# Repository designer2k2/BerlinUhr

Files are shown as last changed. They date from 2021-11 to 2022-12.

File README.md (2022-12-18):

# BerlinUhr
Berlin Uhr or Mengenlehreuhr, a fancy retro style clock that's a bit tricky to read: https://en.wikipedia.org/wiki/Mengenlehreuhr

## What is this

The BerlinUhr is a standalone PCB with all the needed parts on it, just connect power over the USB-C and it will run.

The [ATtiny167](https://www.microchip.com/ATtiny167) receives the actual time from the [DS3231](https://www.maximintegrated.com/en/products/analog/real-time-clocks/DS3231M.html) real time clock chip. Then displays it with 24 leds driven by the [TLC5947](https://www.ti.com/product/TLC5947). The brightness is adopted by measuring the ambient light with a [KPS-3227](https://www.kingbright.com/attachments/file/psearch/000/00/watermark00/KPS-3227SP1C(Ver.9).pdf). 

## Building it

1. PCB, source it with the gerbers: https://github.com/designer2k2/BerlinUhr/tree/main/Berlin_Uhr/gerber
2. Schematic: https://github.com/designer2k2/BerlinUhr/blob/main/Berlin_Uhr/Schematic.pdf
3. BOM, interactive BOM here: https://github.com/designer2k2/BerlinUhr/tree/main/Berlin_Uhr/bom
4. Bootloader, burn the [Micronucleus](https://github.com/micronucleus/micronucleus) Bootloader to the ATtiny167 with ISP: https://github.com/ArminJo/DigistumpArduino 
5. Insert CR1216 battery for the RTC to keep time also while the USB power is gone.
6. Software, upload the Code from the scr folder: https://github.com/designer2k2/BerlinUhr/tree/main/src/berlin-uhr 

## Setting the time

1. The time gets set the first time the code is uploaded to the time from the pc.
2. To change it afterwards, push the A and B buttons on the edge / backside.

## Reading the time

This is special on the Berlin Clock. A practical explanation is given in the wikipedia article: https://en.wikipedia.org/wiki/Mengenlehreuhr#Time_encoding

The Berlin Clock is easy to read after a couple of days :-)

## Modifying it

- The PCB is made with KiCad (6.0.2): http://www.kicad-pcb.org/
- The PCB-Art graphics are made with Inkscape: https://inkscape.org/
- Parts of the graphics are converted to Footprints with svg2mod: https://github.com/mtl/svg2mod
- The BOM is made with InteractiveHtmlBom: https://github.com/openscopeproject/InteractiveHtmlBom

KiCad Version of at least 6.0.2 is needed due to a bug in the KPS-3227 Footprint in older Versions: https://gitlab.com/kicad/libraries/kicad-symbols/-/issues/3164

## How it looks

grafik

Its 17:45 :smiley:

It can hang on a wall or sit on a table with the help of a USB-C phone docking station.

The bare PCB:

grafik

ISP Programming the Bootloader to the ATtiny with the help of a Arduino Uno:

grafik

Populated backside:

grafik

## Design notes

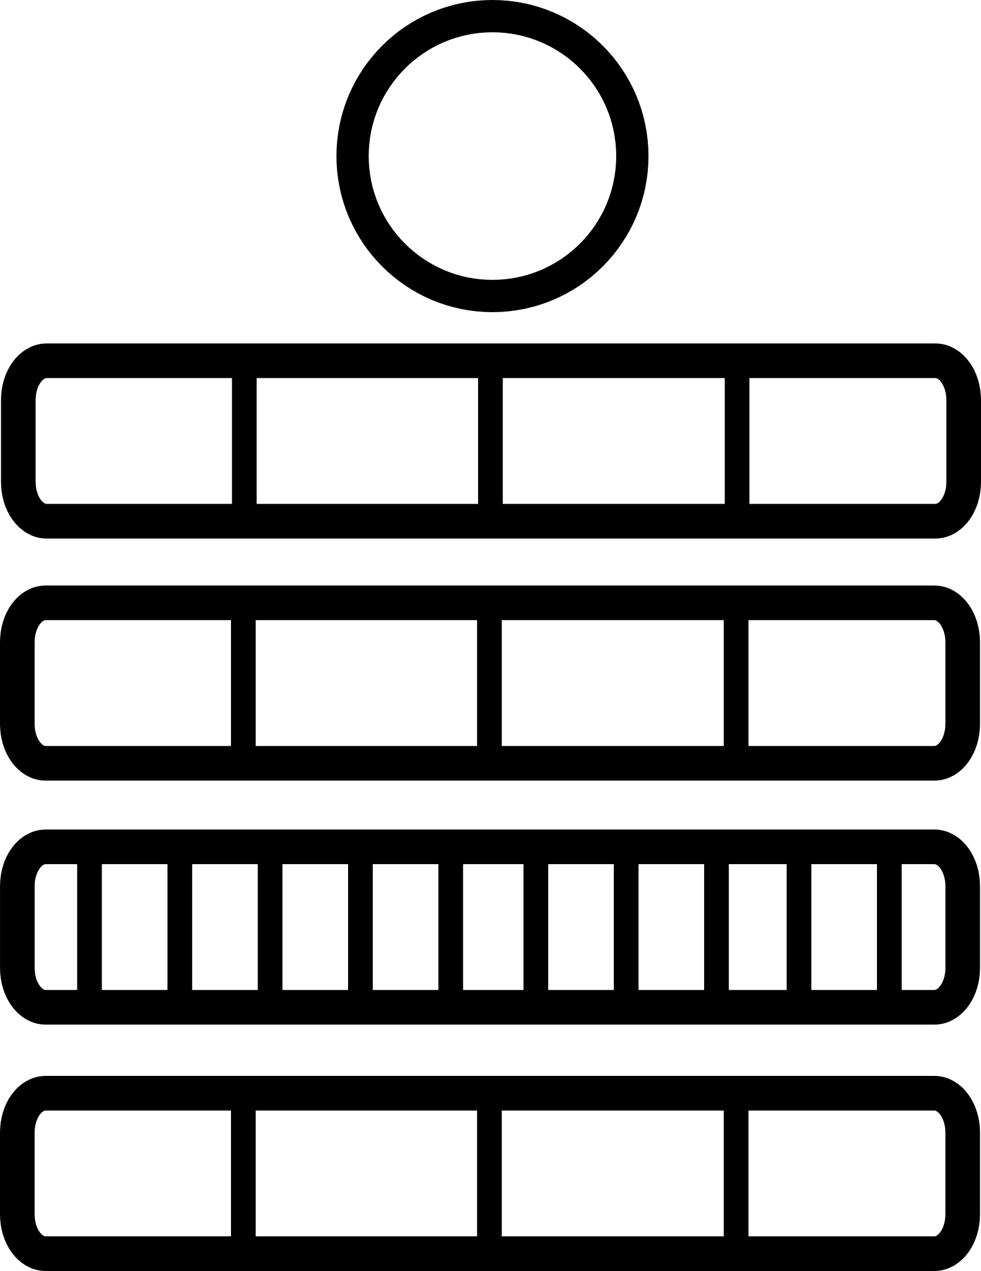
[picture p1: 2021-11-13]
Berlin_Uhr/images/Berlin_Uhr-LED-Frame.png

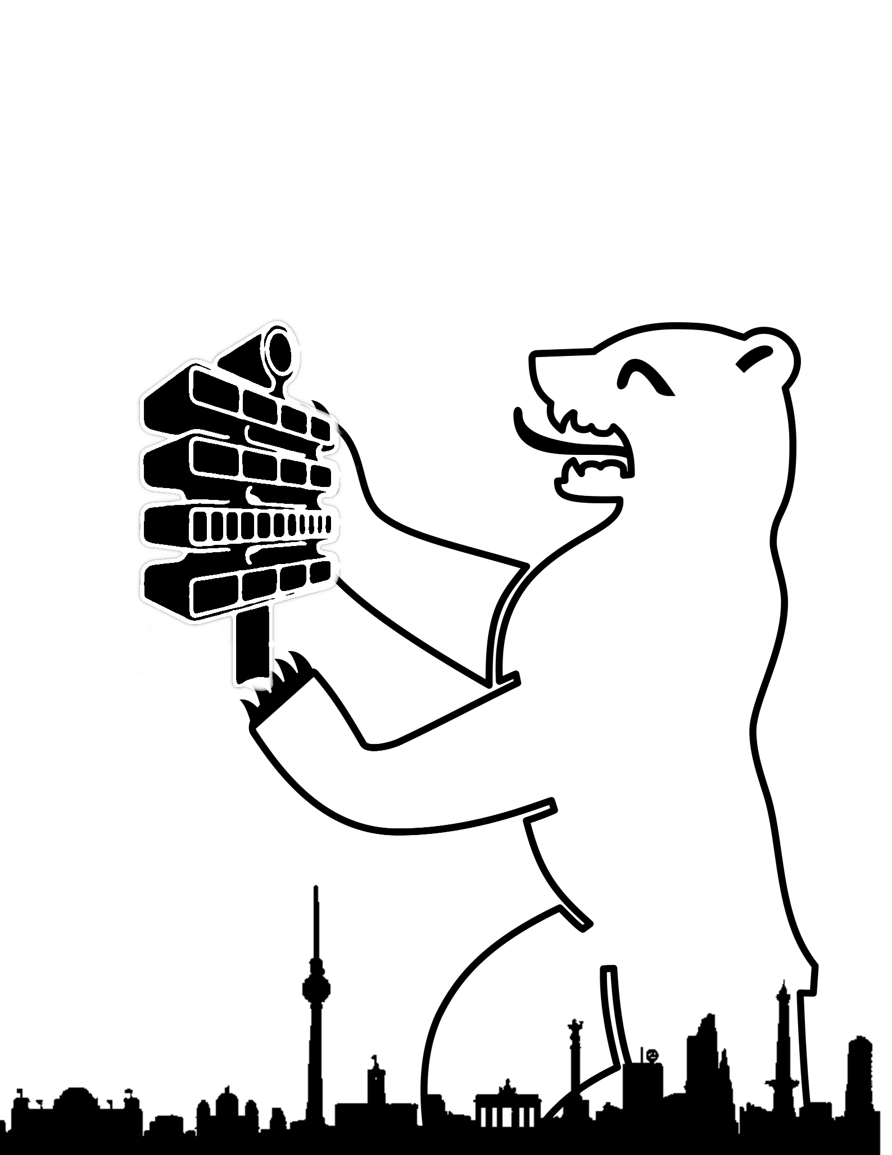
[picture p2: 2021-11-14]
Berlin_Uhr/images/Berlin_Uhr_Frontside.png

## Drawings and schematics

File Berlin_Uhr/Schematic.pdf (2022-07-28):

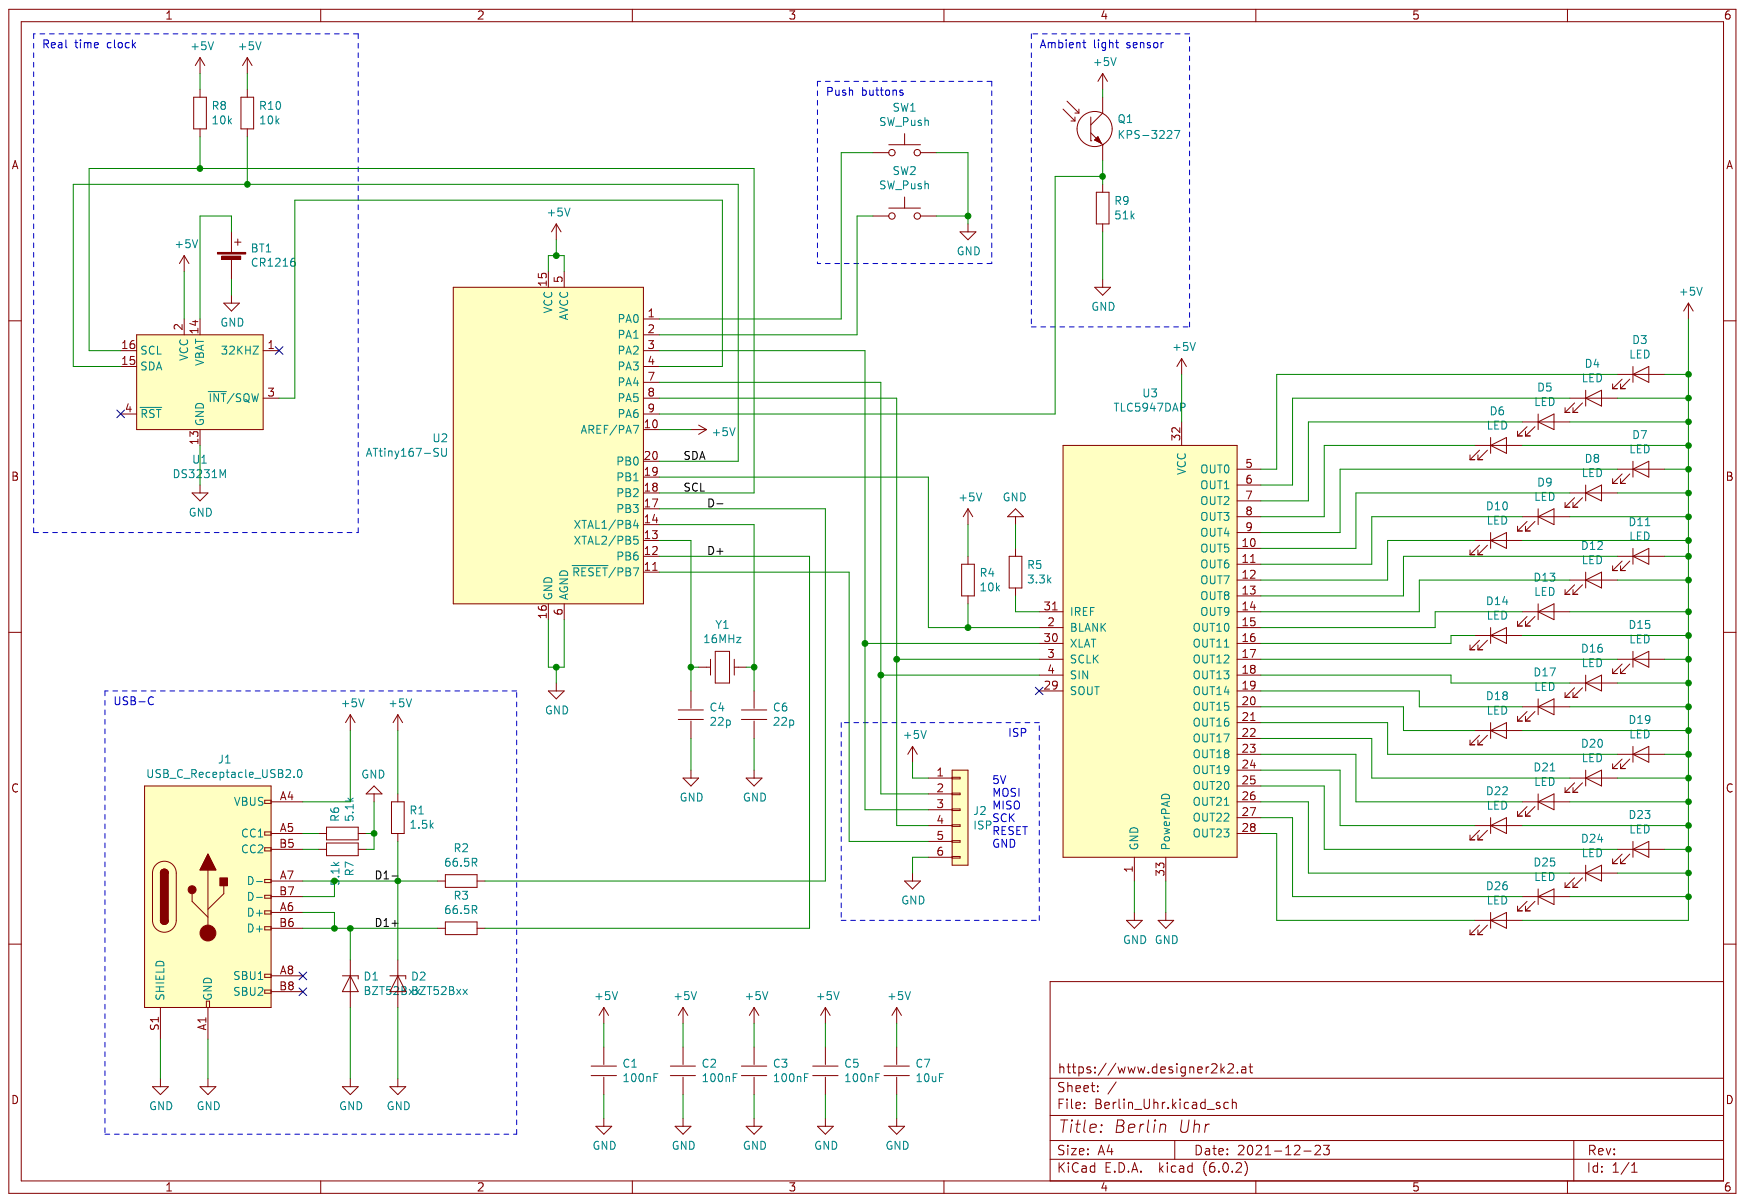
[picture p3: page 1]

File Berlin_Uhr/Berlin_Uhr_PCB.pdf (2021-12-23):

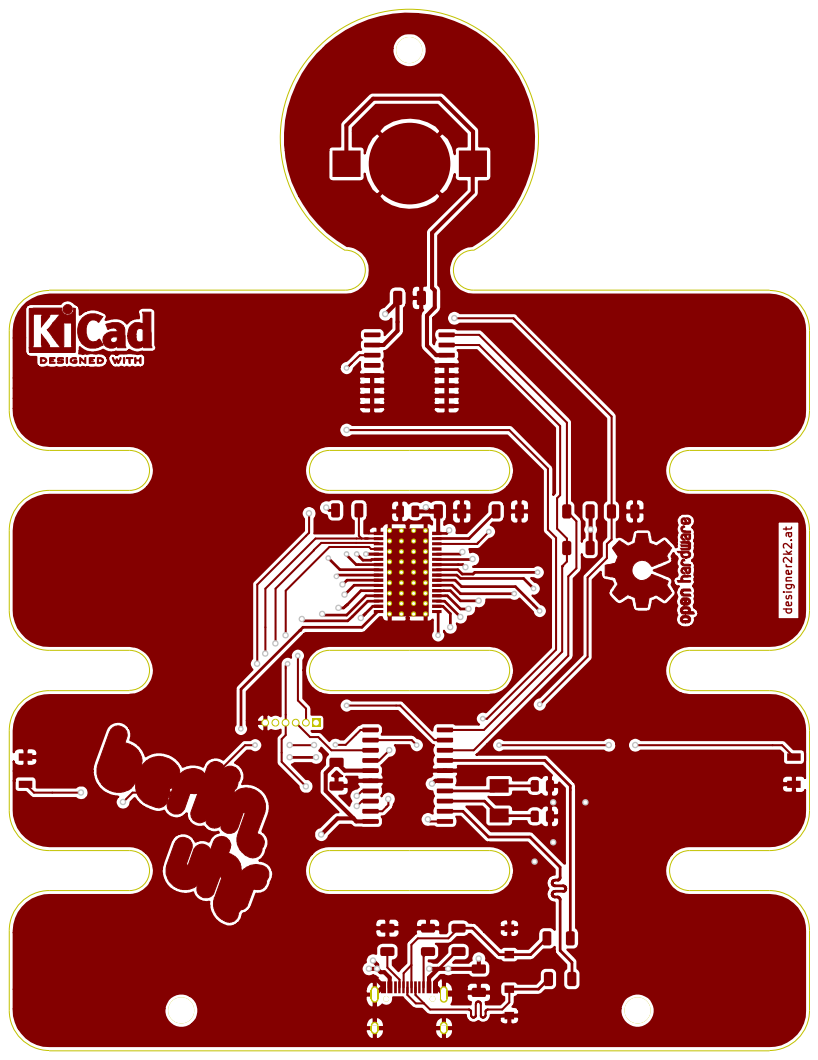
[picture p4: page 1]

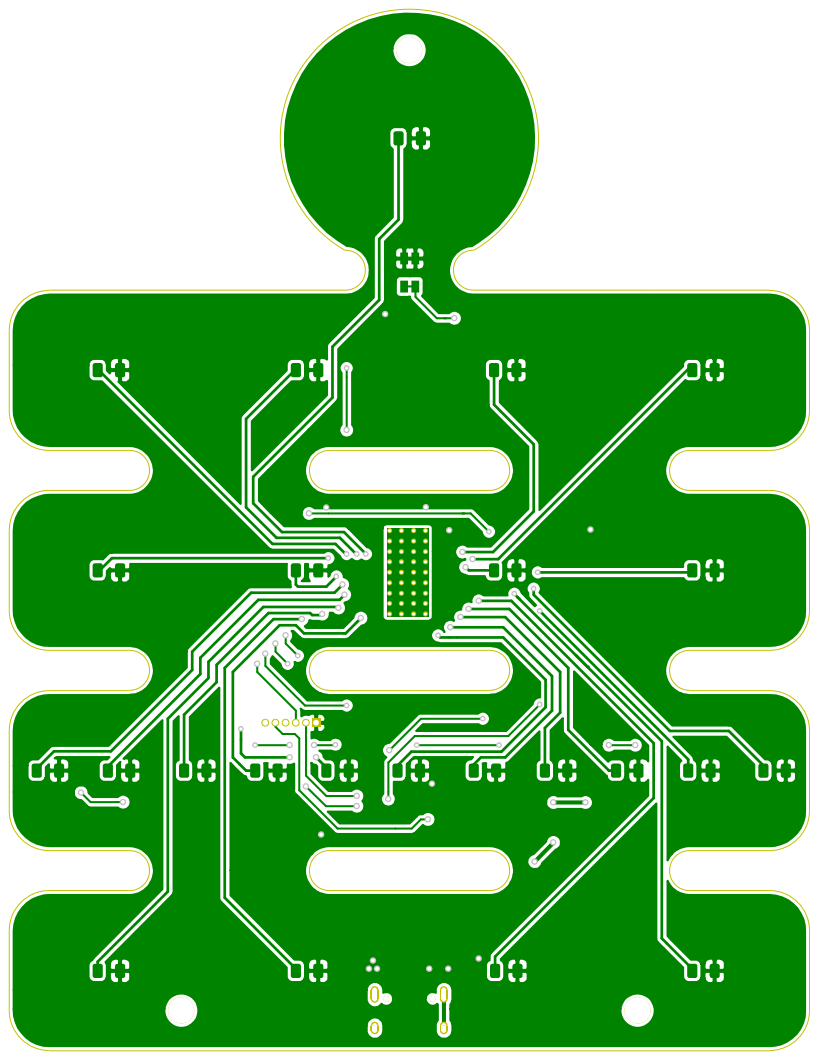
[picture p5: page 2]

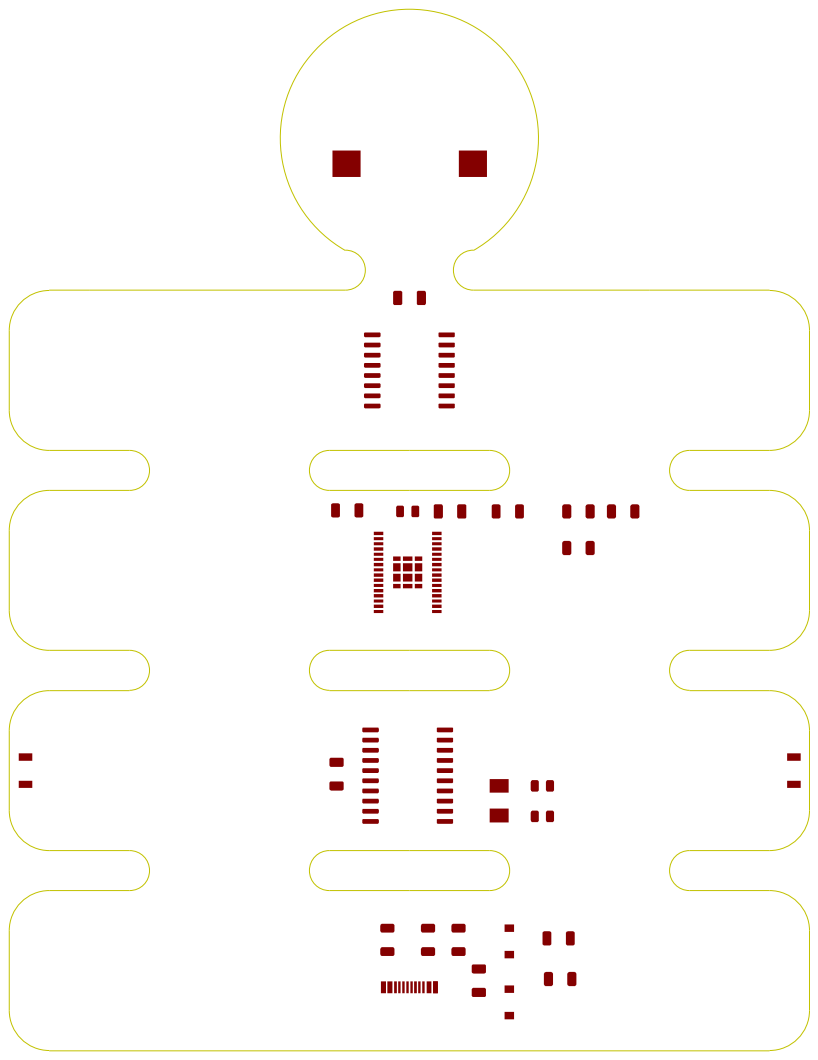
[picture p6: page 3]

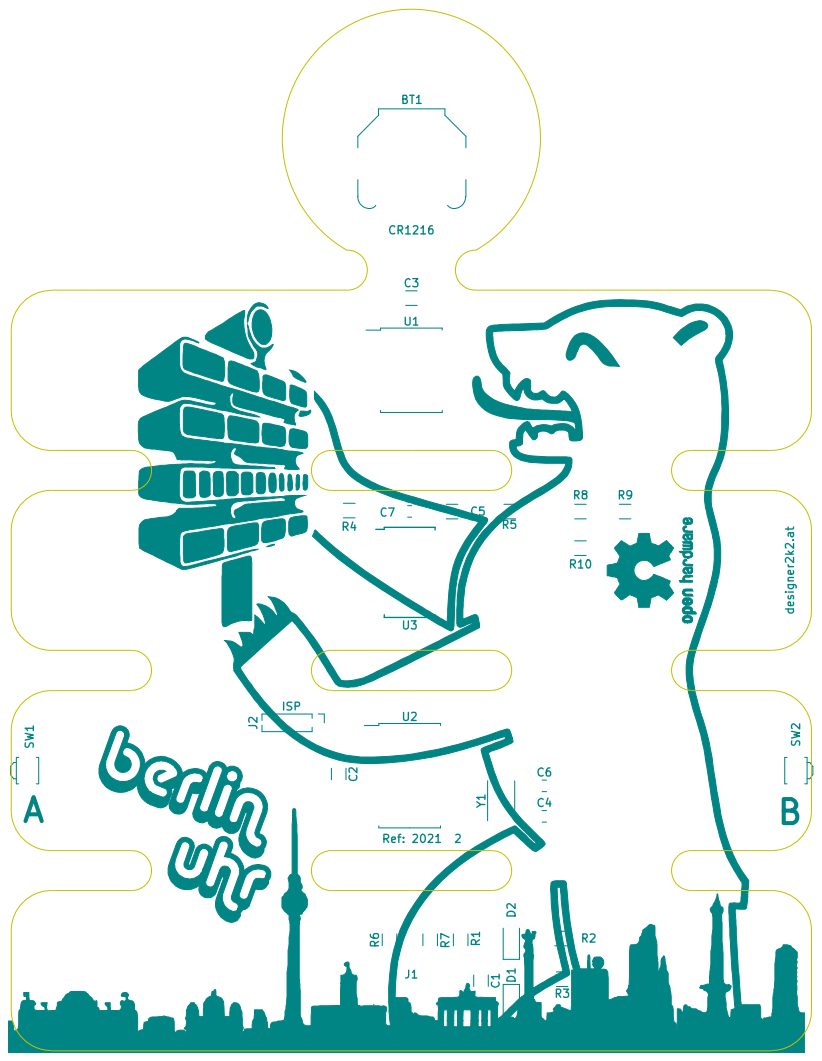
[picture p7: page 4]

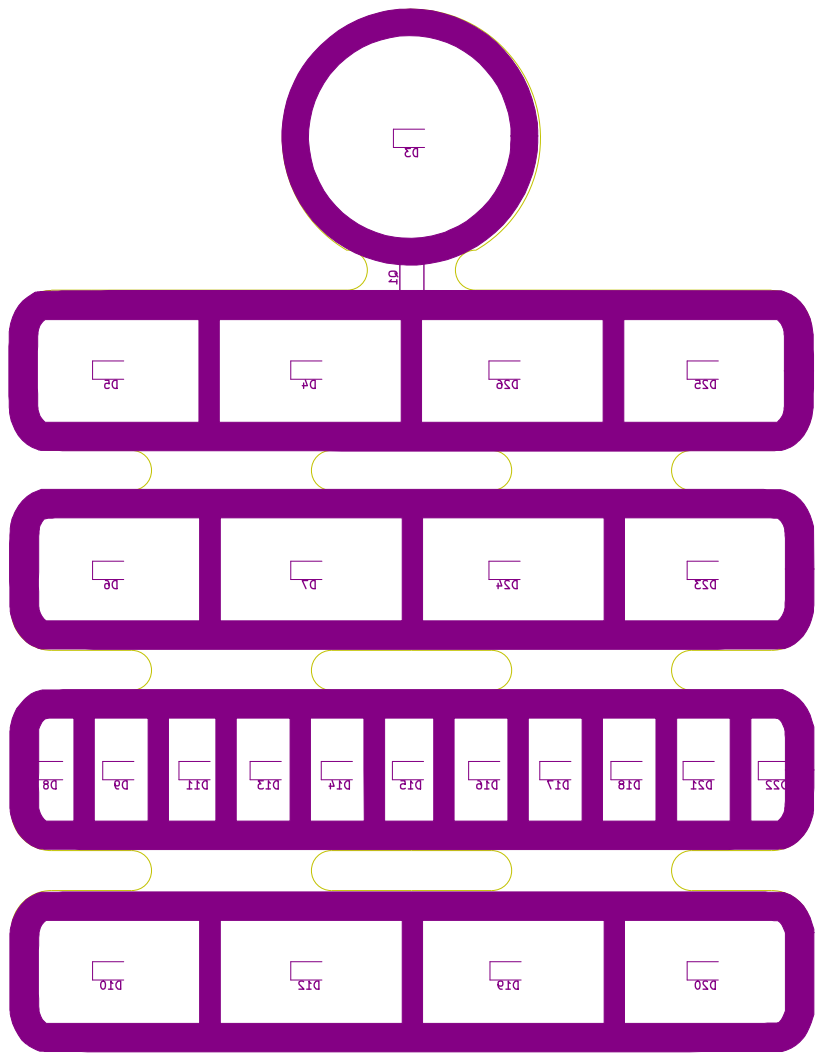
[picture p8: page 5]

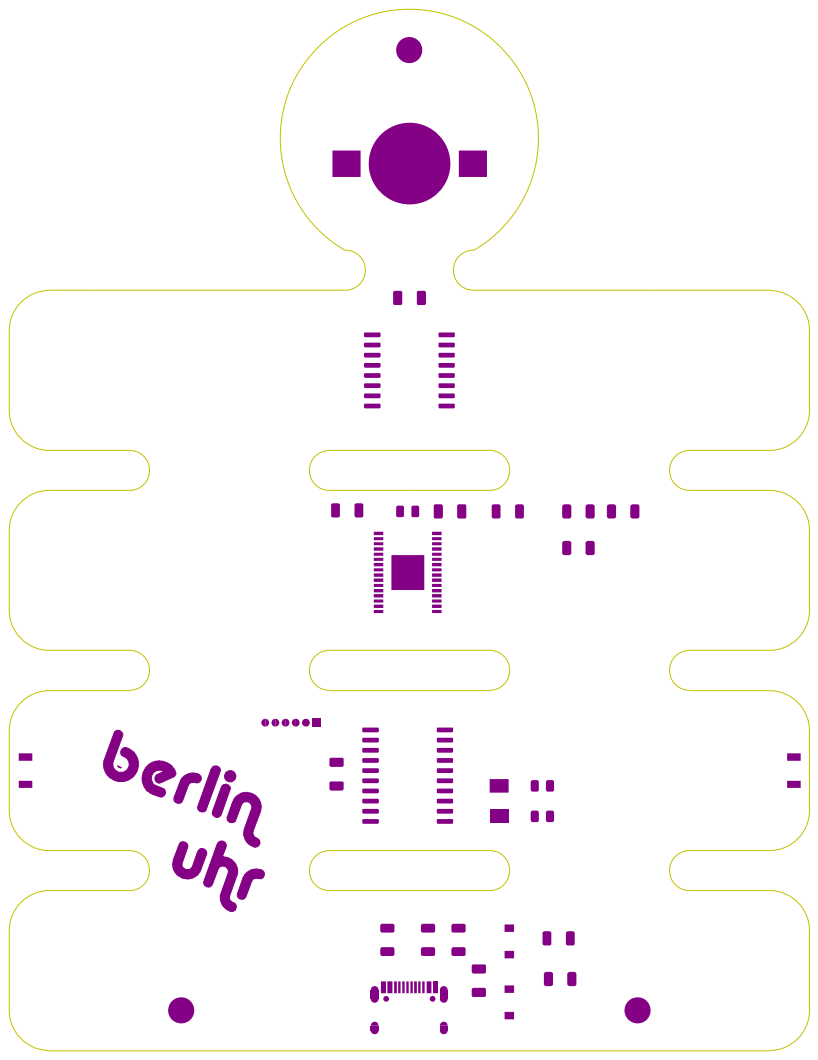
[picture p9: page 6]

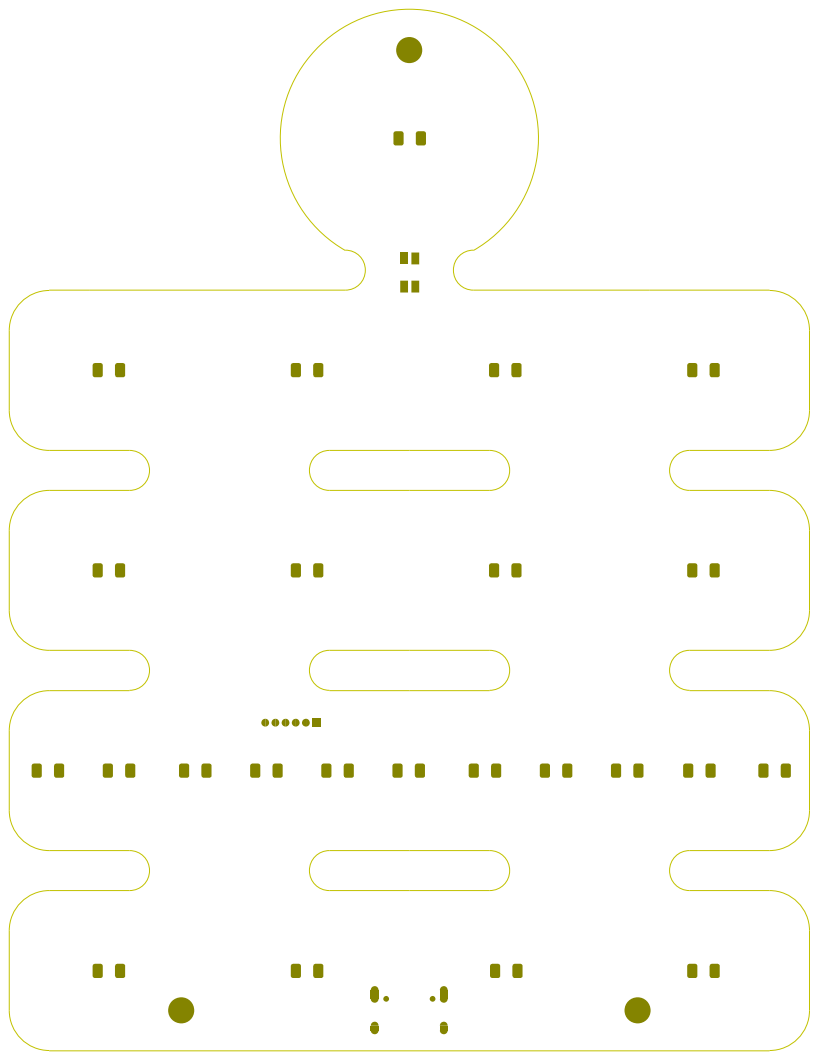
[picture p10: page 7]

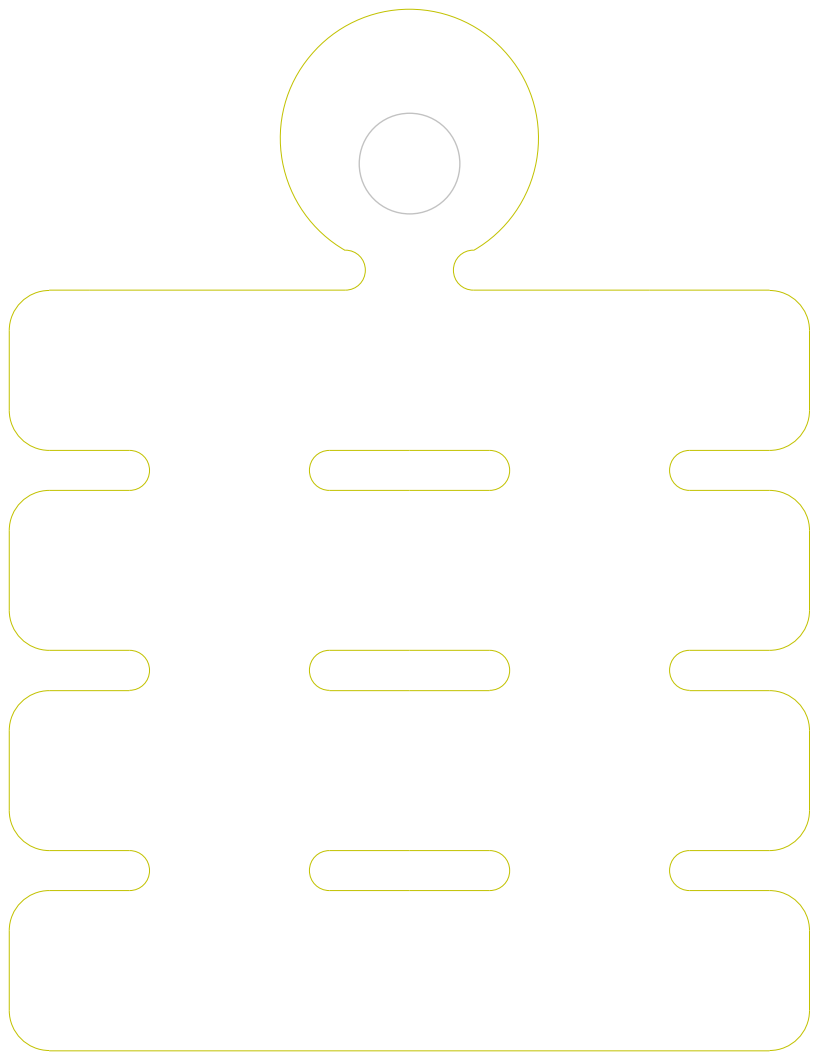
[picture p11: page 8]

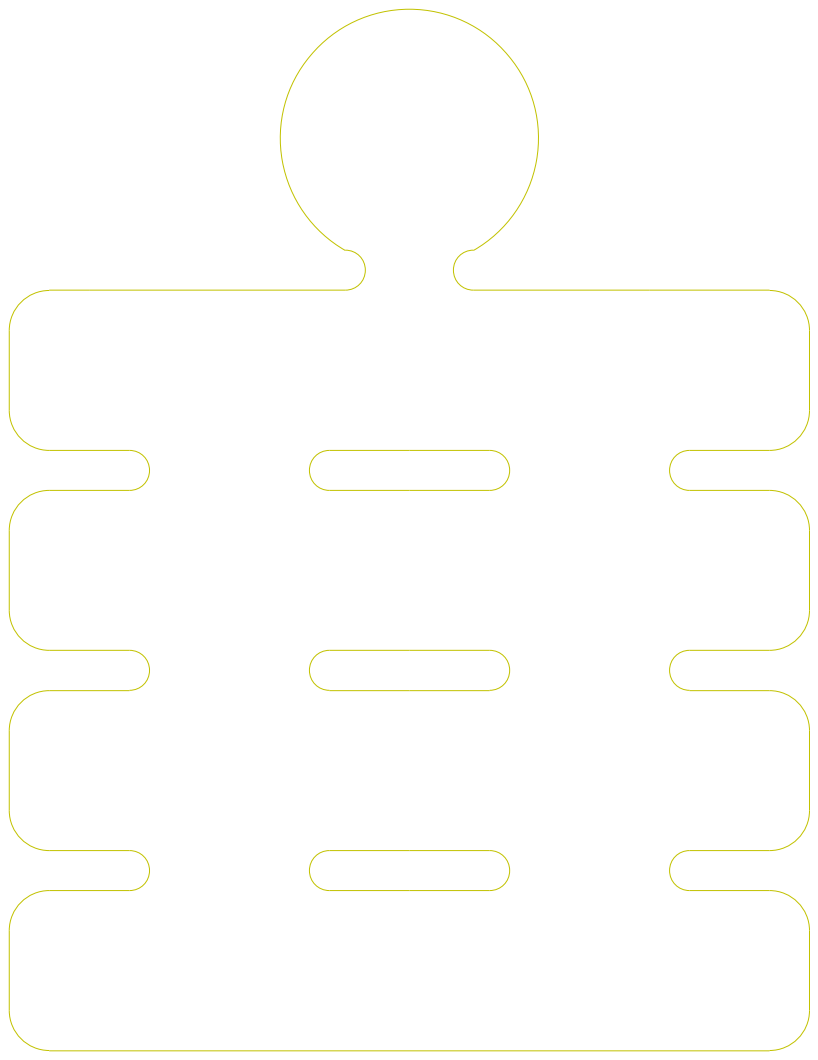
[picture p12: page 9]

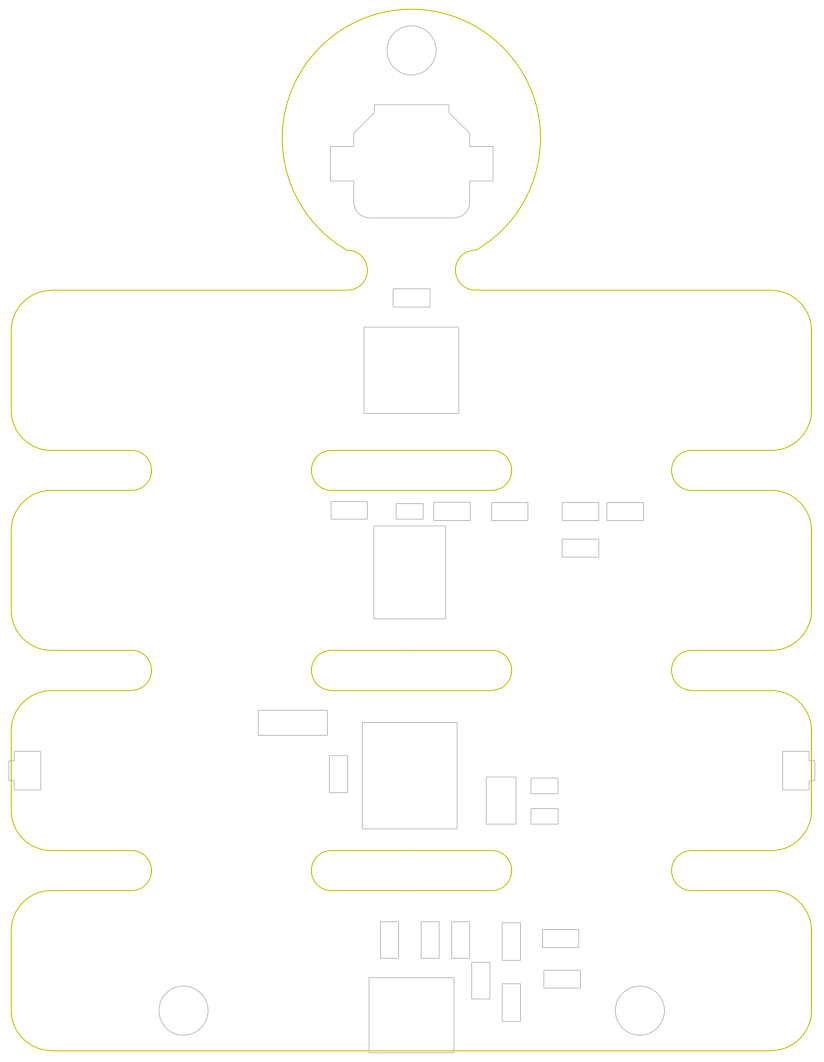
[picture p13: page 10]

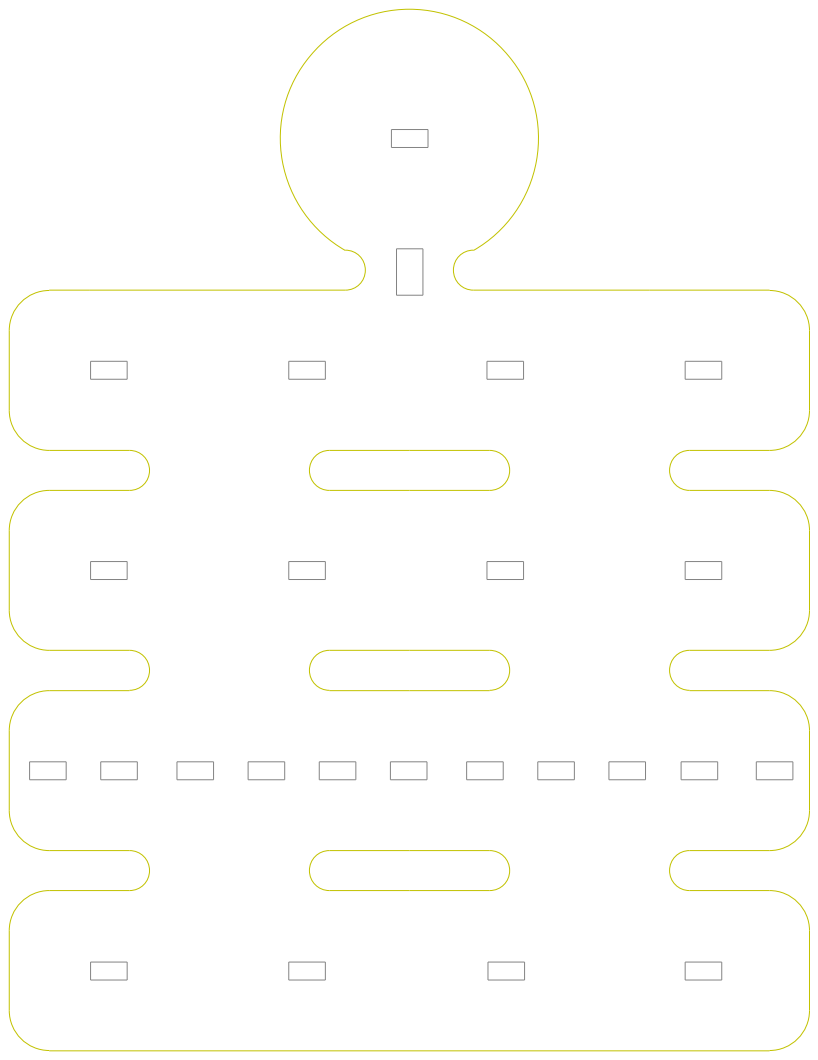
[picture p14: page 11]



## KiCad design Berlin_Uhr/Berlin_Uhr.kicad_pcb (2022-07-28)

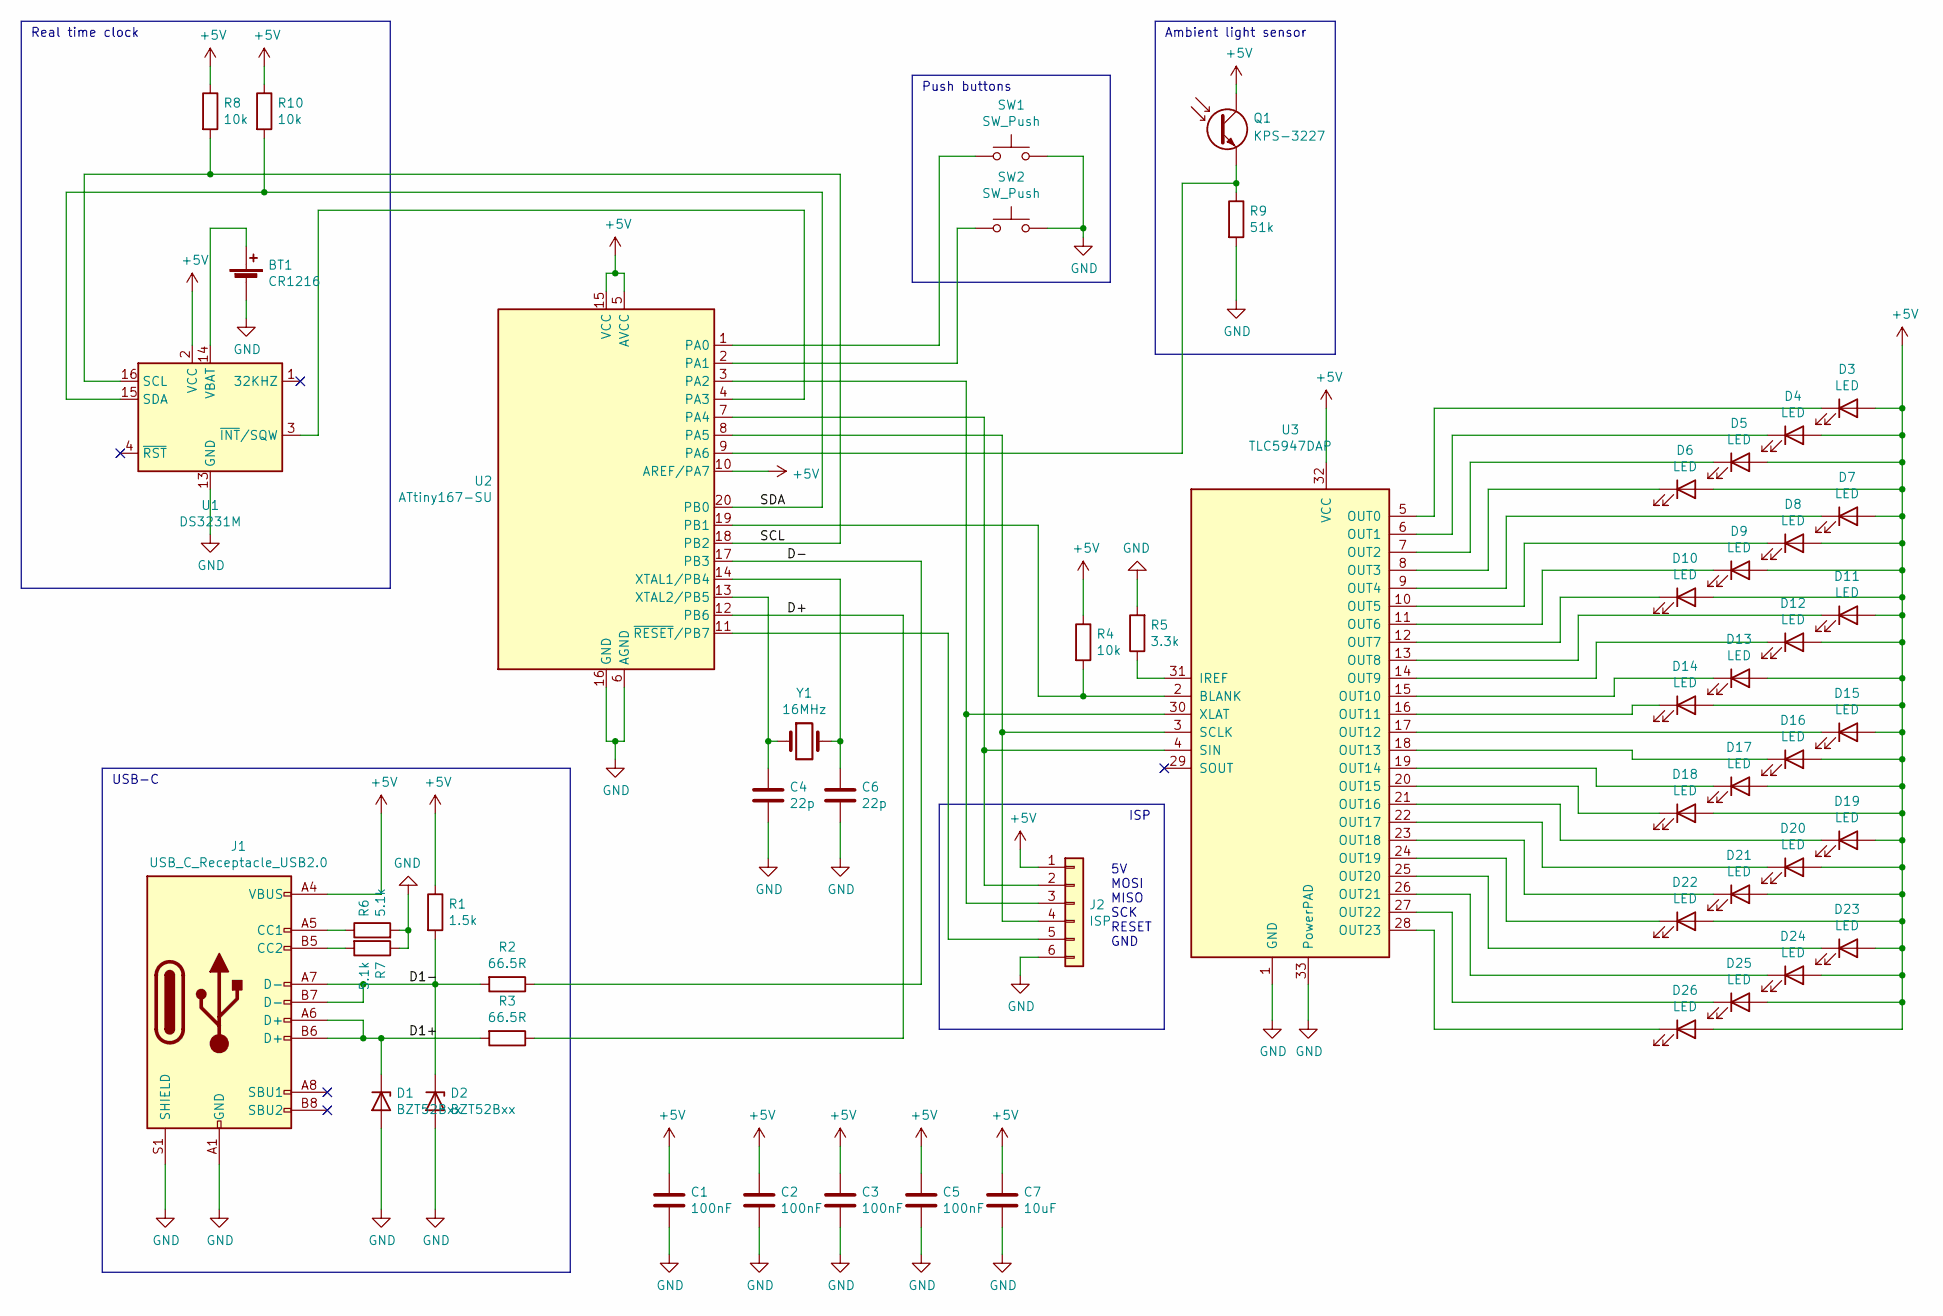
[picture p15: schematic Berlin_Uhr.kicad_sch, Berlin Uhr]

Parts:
BT1: CR1216; BatteryHolder_Keystone_3000_1x12mm
C1, C2, C3, C5: 100nF; C_1206_3216Metric
C4, C6: 22p; C_0805_2012Metric
C7: 10uF; C_0805_2012Metric
D1, D2: BZT52Bxx; D_SOD-123
D3, D4, D5, D6, D7, D8, D9, D10, D11, D12, D13, D14, D15, D16, D17, D18, D19, D20, D21, D22, D23, D24, D25, D26: LED; D_1206_3216Metric
J1: USB_C_Receptacle_USB2.0; USB_C_Receptacle_HRO_TYPE-C-31-M-12; DigiKey 900-2171790001CT-ND
J2: ISP; PinHeader_1x06_P1.27mm_Vertical
Q1: KPS-3227; Kingbright_KPS-3227
R1: 1.5k; R_1206_3216Metric
R2, R3: 66.5R; R_1206_3216Metric
R4, R8, R10: 10k; R_1206_3216Metric
R5: 3.3k; R_1206_3216Metric
R6, R7: 5.1k; R_1206_3216Metric
R9: 51k; R_1206_3216Metric
SW1, SW2: SW_Push; SW_SPST_B3U-3000P
U1: DS3231M; SOIC-16W_7.5x10.3mm_P1.27mm
U2: ATtiny167-SU; SOIC-20W_7.5x12.8mm_P1.27mm
U3: TLC5947DAP; HTSSOP-32-1EP_6.1x11mm_P0.65mm_EP5.2x11mm_Mask4.11x4.36mm_T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
Y1: 16MHz; Crystal_SMD_TXC_7A-2Pin_5x3.2mm

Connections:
+5V: C1.1, C2.1, C3.1, C5.1, C7.1, D3.2 (A), D4.2 (A), D5.2 (A), D6.2 (A), D7.2 (A), D8.2 (A), D9.2 (A), D10.2 (A), D11.2 (A), D12.2 (A), D13.2 (A), D14.2 (A), D15.2 (A), D16.2 (A), D17.2 (A), D18.2 (A), D19.2 (A), D20.2 (A), D21.2 (A), D22.2 (A), D23.2 (A), D24.2 (A), D25.2 (A), D26.2 (A), J1.A4 (VBUS), J1.A9 (VBUS), J1.B4 (VBUS), J1.B9 (VBUS), J2.1, Q1.1, Q1.3, R1.1, R4.1, R8.1, R10.1, U1.2 (VCC), U2.5 (AVCC), U2.10 (AREF/PA7), U2.15 (VCC), U3.32 (VCC)
/D1+: D1.1 (K), J1.A6 (D+), J1.B6 (D+), R3.2
/D1-: D2.1 (K), J1.A7 (D-), J1.B7 (D-), R1.2, R2.2
/D+: R3.1, U2.12 (PB6)
/D-: R2.1, U2.17 (PB3)
/SCL: R8.2, U1.16 (SCL), U2.18 (PB2)
/SDA: R10.2, U1.15 (SDA), U2.20 (PB0)
GND: BT1.2 (-), C1.2, C2.2, C3.2, C4.2, C5.2, C6.2, C7.2, D1.2 (A), D2.2 (A), J1.A1 (GND), J1.A12 (GND), J1.B1 (GND), J1.B12 (GND), J1.S1 (SHIELD), J2.6, R5.2, R6.2, R7.1, R9.2, SW1.2, SW2.2, U1.5 (GND), U1.6 (GND), U1.7 (GND), U1.8 (GND), U1.9 (GND), U1.10 (GND), U1.11 (GND), U1.12 (GND), U1.13 (GND), U2.6 (AGND), U2.16 (GND), U3.1 (GND), U3.33 (PowerPAD)
unnamed: BT1.1 (+), U1.14 (VBAT)
unnamed: C4.1, U2.13 (XTAL2/PB5), Y1.1
unnamed: C6.1, U2.14 (XTAL1/PB4), Y1.2
unnamed: D3.1 (K), U3.5 (OUT0)
unnamed: D4.1 (K), U3.6 (OUT1)
unnamed: D5.1 (K), U3.7 (OUT2)
unnamed: D6.1 (K), U3.8 (OUT3)
unnamed: D7.1 (K), U3.9 (OUT4)
unnamed: D8.1 (K), U3.10 (OUT5)
unnamed: D9.1 (K), U3.11 (OUT6)
unnamed: D10.1 (K), U3.12 (OUT7)
unnamed: D11.1 (K), U3.13 (OUT8)
unnamed: D12.1 (K), U3.14 (OUT9)
unnamed: D13.1 (K), U3.15 (OUT10)
unnamed: D14.1 (K), U3.16 (OUT11)
unnamed: D15.1 (K), U3.17 (OUT12)
unnamed: D16.1 (K), U3.18 (OUT13)
unnamed: D17.1 (K), U3.19 (OUT14)
unnamed: D18.1 (K), U3.20 (OUT15)
unnamed: D19.1 (K), U3.21 (OUT16)
unnamed: D20.1 (K), U3.22 (OUT17)
unnamed: D21.1 (K), U3.23 (OUT18)
unnamed: D22.1 (K), U3.24 (OUT19)
unnamed: D23.1 (K), U3.25 (OUT20)
unnamed: D24.1 (K), U3.26 (OUT21)
unnamed: D25.1 (K), U3.27 (OUT22)
unnamed: D26.1 (K), U3.28 (OUT23)
unnamed: J1.A5 (CC1), R6.1
unnamed: J1.B5 (CC2), R7.2
unnamed: J2.2, U2.7 (PA4), U3.4 (SIN)
unnamed: J2.3, U2.3 (PA2), U3.30 (XLAT)
unnamed: J2.4, U2.8 (PA5), U3.3 (SCLK)
unnamed: J2.5, U2.11 (~RESET/PB7)
unnamed: R4.2, U2.19 (PB1), U3.2 (BLANK)
unnamed: R5.1, U3.31 (IREF)
unnamed: Q1.2, Q1.4, R9.1, U2.9 (PA6)
unnamed: SW1.1, U2.1 (PA0)
unnamed: SW2.1, U2.2 (PA1)
unnamed: U1.3 (~INT/SQW), U2.4 (PA3)

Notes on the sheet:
Ambient light sensor
Real time clock
USB-C
Push buttons
ISP
5V MOSI MISO SCK RESET GND

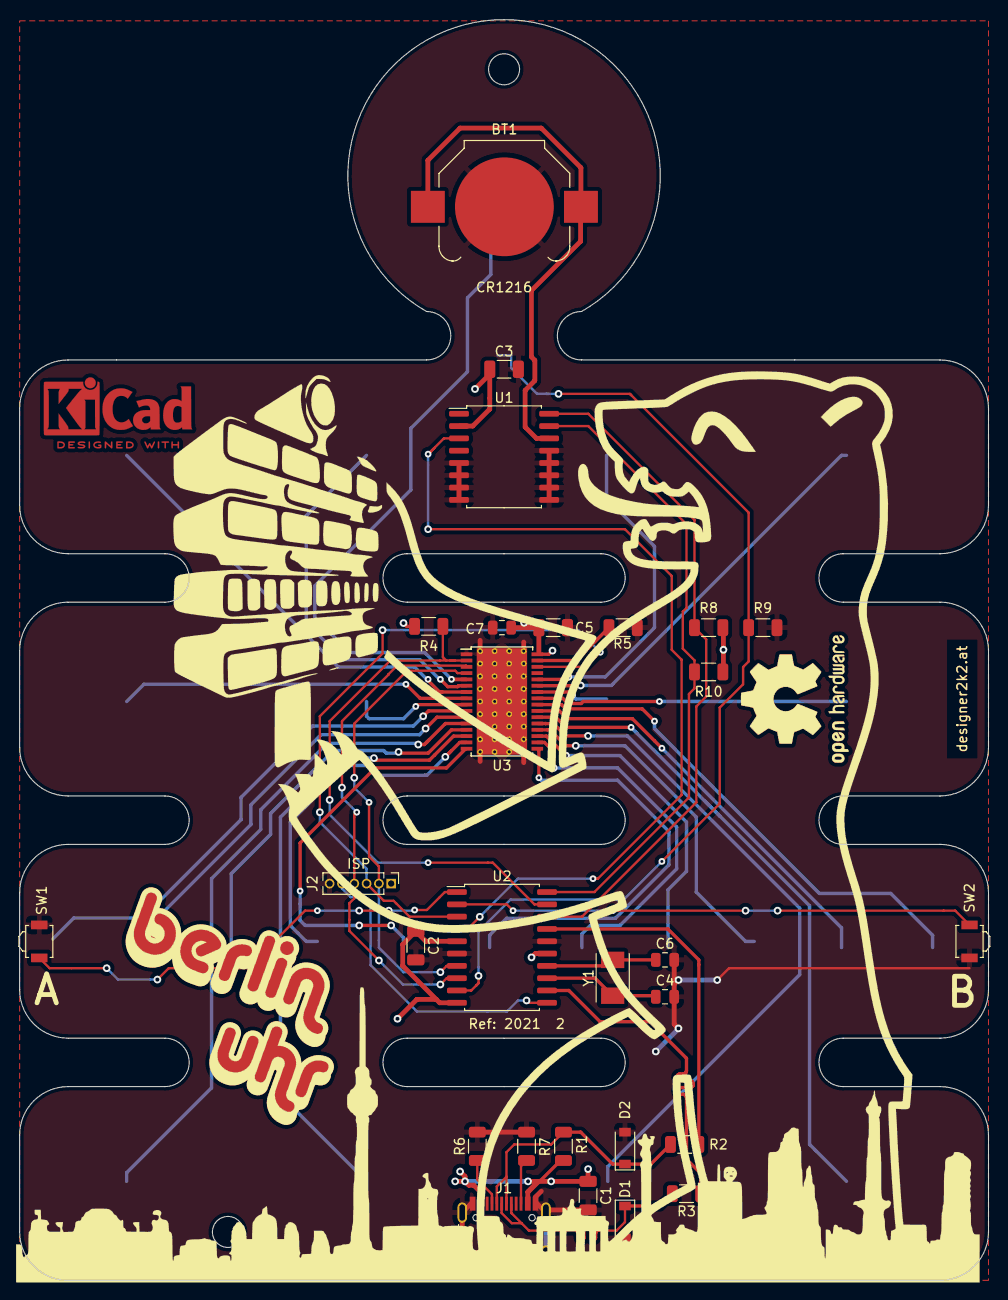
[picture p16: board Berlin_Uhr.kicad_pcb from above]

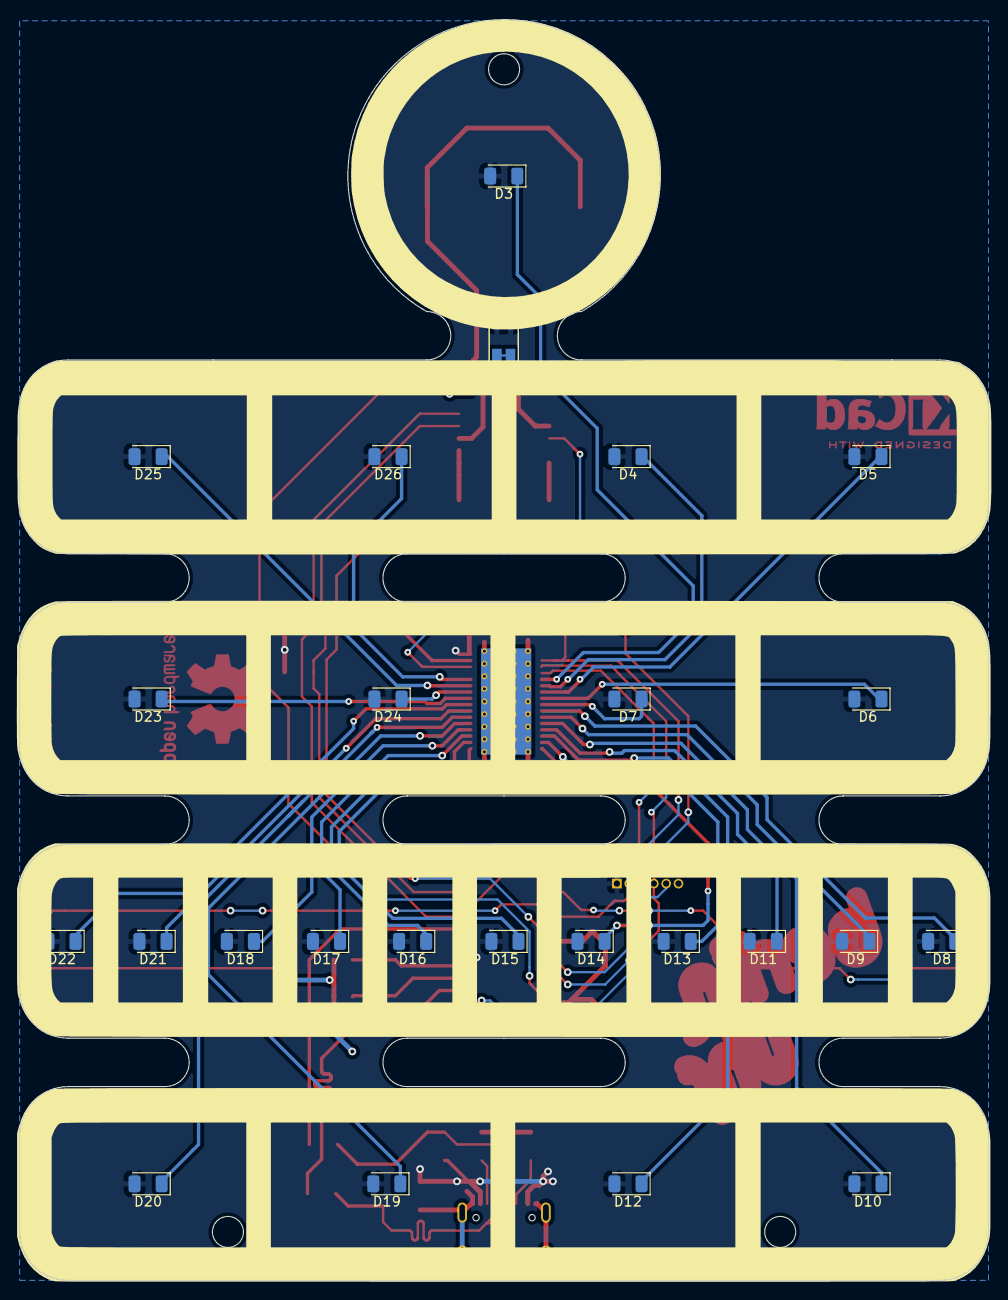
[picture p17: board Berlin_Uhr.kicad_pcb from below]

Board: 2 copper layers, 100.0 x 130.1 mm, 54 parts (25 on the bottom side), 47 nets.

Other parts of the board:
BerlinUhr: G***; BerlinUhrLogo

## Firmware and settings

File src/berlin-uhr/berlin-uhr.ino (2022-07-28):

// Copyright (C) 2022 Oliver Rehfeld, Stephan Martin
// This file is part of Berlin Uhr <https://github.com/designer2k2/BerlinUhr>.
//
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
// Howto:
// At the time of writing this code was uploaded using Arduino IDE 1.8.19
// And the ATTinyCore 1.5.2 https://github.com/SpenceKonde/ATTinyCore set to:
// ATtiny167 (Micronucleus / DigiSpark Pro)

// --------------------------------------------------------------------------------
// -- Includes
// --------------------------------------------------------------------------------
#include <Adafruit_TLC5947.h> // https://github.com/adafruit/Adafruit_TLC5947/
#include <DS3231.h> // https://github.com/NorthernWidget/DS3231
#include <Wire.h>
#include <EEPROM.h>

// --------------------------------------------------------------------------------
// -- Global Variables for Tests
// --------------------------------------------------------------------------------
#define Delay4Tests 500

// --------------------------------------------------------------------------------
// -- Global Variables
// --------------------------------------------------------------------------------
#define BtnAPin 6
#define BtnBPin 7

#define LedPinOffset 3
#define SecLedPin 3
const int Hour1Pin[4] = {23, 24, 7, 6};
const int Hour5Pin[4] = {25, 26, 4, 5};
const int Min5Pin[11] = {22, 21, 18, 17, 16, 15, 14, 13, 11, 9, 8};
const int Min1Pin[4] = {20, 19, 12, 10};

// --------------------
// Light Sensor
// Brightness
// --------------------
#define LightSensorPin 6
#define LightSensorMax 1024
#define BrightMin 20
#define BrightMax 300 // max 4096
// 1 = linear, 2 = log, 3 = x^2, 4 = sq(x)
#define BrightCurve 1
// 0 = off, 1 = middle to last, 2 = FIFO
#define BrightSmooth 2
#define BrightFifoNum 10
int m_iBright = 5;
int m_iBrightFifo[BrightFifoNum];
int m_iBrightFifoIdx = 0;

// --------------------
// RTC
// --------------------
DS3231 m_oClock;
int m_iMin, m_iHour;
bool m_bH12, m_bPM;

// --------------------
// -- LED Controller
// --------------------
#define Data   10    // PA4
#define Clock   11   // PA5
#define Latch   8   // PA2
#define oe  1      // set to -1 to not use the enable pin (its optional)
Adafruit_TLC5947 oTLC = Adafruit_TLC5947(1, Clock, Data, Latch);

// --------------------------------------------------------------------------------
// -- Set LEDs
// --------------------------------------------------------------------------------
void setBright()
{
  int iBrightTotal = 0;
  uint32_t uiBright = analogRead(LightSensorPin);

  // brightness curve
  switch (BrightCurve) {
    // linear
    case 1:
    default:
      uiBright = 4 * uiBright;
      break;
      
    // log
    case 2:
      // Read the light sensor value, log convert:
      uiBright = sq(uiBright);
      uiBright = uiBright / 256;
      break;

    // x^2
    case 3:
      uiBright = uiBright * uiBright / 400 + BrightMin;
      break;

    // sq
    case 4:
      uiBright = sq(uiBright) * 5 + BrightMin;
  }

  // smoothing
  switch (BrightSmooth) {
    case 1:
      uiBright = (uiBright + m_iBright) / 2;
      break;

    case 2:
      m_iBrightFifoIdx++;
      if (m_iBrightFifoIdx == BrightFifoNum) {
        m_iBrightFifoIdx = 0;
      }
      m_iBrightFifo[m_iBrightFifoIdx] = uiBright;
      for (int i = 0; i < BrightFifoNum; i++) {
        iBrightTotal += m_iBrightFifo[i];
      }
      uiBright = iBrightTotal / BrightFifoNum;
      
      break;

    default:
      break;
  }

  m_iBright = (int)uiBright;

  // set to minimum
  if (m_iBright < BrightMin) {
    m_iBright = BrightMin;
  }
  // set to maximum
  if (m_iBright > BrightMax) {
    m_iBright = BrightMax;
  }
}

void setLedOn(int iLedPin)
{
  if (iLedPin < LedPinOffset) {
    return;
  }
  
  oTLC.setPWM((iLedPin - LedPinOffset), m_iBright);
}

void setLedOff(int iLedPin)
{
  oTLC.setPWM((iLedPin - LedPinOffset), 0);
}

// --------------------------------------------------------------------------------
// -- Set Sec, Min, Hour LEDs
// --------------------------------------------------------------------------------
void setSecLed(int iSec)
{
  // Sec even?
  if ((iSec % 2) == 0) {
    // -- LED on
    setLedOn(SecLedPin);
  }
  else {
    // -- LED off
    setLedOff(SecLedPin);
  }
}

void setMinLed(int iMin)
{
  m_iMin = iMin;

  // --------------------------------------------
  for (int i = 0; i < 11; i++) {
    // set Min5 off
    setLedOff(Min5Pin[i]);
  }
  for (int i = 0; i < 4; i++) {
    // set Min1 off
    setLedOff(Min1Pin[i]);
  }
  
  // --------------------------------------------
  int iRest = m_iMin % 5;
  if (iRest != 0) {
    for (int i = 0; i < iRest; i++) {
      // set Min1 on
      setLedOn(Min1Pin[i]);
    }
  }

  // --------------------------------------------
  int iCount5 = (m_iMin - iRest) / 5;
  for (int i = 0; i < iCount5; i++) {
    // set Min5 on
    setLedOn(Min5Pin[i]);
  }
}

void setHourLed(int iHour)
{
  m_iHour = iHour;

  // --------------------------------------------
  for (int i = 0; i < 4; i++) {
    // set Hours off
    setLedOff(Hour5Pin[i]);
  }
  for (int i = 0; i < 4; i++) {
    // set Hours off
    setLedOff(Hour1Pin[i]);
  }
  
  // --------------------------------------------
  int iRest = m_iHour % 5;
  if (iRest != 0) {
    for (int i = 0; i < iRest; i++) {
      // set Hour1 on
      setLedOn(Hour1Pin[i]);
    }
  }

  // --------------------------------------------
  int iCount5 = (m_iHour - iRest) / 5;
  for (int i = 0; i < iCount5; i++) {
    // set Hour5 on
    setLedOn(Hour5Pin[i]);
  }
}

// --------------------------------------------------------------------------------
// -- change time
// --------------------------------------------------------------------------------
void incMin()
{
  int iMin = m_oClock.getMinute();
  int iHour = m_oClock.getHour(m_bH12, m_bPM);

  if (iMin == 59) {
    iMin = 0;
    iHour++;
    if (iHour == 24) {
      iHour = 0;
    }
  }
  else {
    iMin++;
  }

  m_oClock.setHour(iHour);
  m_oClock.setMinute(iMin);
  m_oClock.setSecond(0);
}

void decMin()
{
  int iMin = m_oClock.getMinute();
  int iHour = m_oClock.getHour(m_bH12, m_bPM);

  if (iMin == 0) {
    iMin = 59;
    iHour--;
    if (iHour < 0) {
      iHour = 23;
    }
  }
  else {
    iMin--;
  }

  m_oClock.setHour(iHour);
  m_oClock.setMinute(iMin);
  m_oClock.setSecond(0);
}

// --------------------------------------------------------------------------------
// -- Tests
// --------------------------------------------------------------------------------
void testLedNumSeq()
{
  for (int i = LedPinOffset; i <= (23 + LedPinOffset); i++) {
    setLedOff(i);

    oTLC.write();
  }

  delay(Delay4Tests);

  m_iBright = 250;
  while (m_iBright <= 1000) {
    for (int i = LedPinOffset; i <= (23 + LedPinOffset); i++) {
      setLedOn(i);
      oTLC.write();
      delay(Delay4Tests);
      setLedOff(i);
      oTLC.write();
    }

    m_iBright += 250;
  }

  m_iBright = 500;
}

void testSim24h()
{
  m_iBright = 500;

  setSecLed(0);
  
  for (int h = 0; h < 24; h++) {
    for (int m = 0; m < 60; m++) {
      setHourLed(h);
      setMinLed(m);
    
      oTLC.write();
    
      delay(200);
    }
  }
}

// --------------------------------------------------------------------------------
// -- Setup
// --------------------------------------------------------------------------------
void setCompileTime()
{
  const int iAddr = 0;
  const int iFirstStart = 1;

  // TODO: check RTC time is older than compile time
  
  if (EEPROM.read(iAddr) != iFirstStart) {
    DateTime oDT(__DATE__, __TIME__);
    
    m_oClock.setYear(oDT.year());
    m_oClock.setMonth(oDT.month());
    m_oClock.setDate(oDT.day());
    m_oClock.setHour(oDT.hour());
    m_oClock.setMinute(oDT.minute());
    m_oClock.setSecond(0);
    
    EEPROM.write(iAddr, iFirstStart); 

    delay(500);
  }
}

void setup()
{
  // Start the I2C interface
  Wire.begin();
  Wire.setClock(400000);

  pinMode(BtnAPin, INPUT_PULLUP);
  pinMode(BtnBPin, INPUT_PULLUP);

  m_oClock.setClockMode(false);
  
  oTLC.begin();
  pinMode(oe, OUTPUT);
  digitalWrite(oe, LOW);

  m_iMin = 0;
  m_iHour = 0;

  setCompileTime();
  
  for (int i = LedPinOffset; i <= (23 + LedPinOffset); i++) {
    setLedOff(i);
  }

  for (int i = 0; i < BrightFifoNum; i++) {
    m_iBrightFifo[i] = 20;
  }
}

// --------------------------------------------------------------------------------
// -- Main Loop
// --------------------------------------------------------------------------------
void loop()
{
/*
  testSim24h();
*/

  if (!digitalRead(BtnAPin)) {
    incMin();
  }
  if (!digitalRead(BtnBPin)) {
    decMin();
  }

  setBright();

  setSecLed(m_oClock.getSecond());
  setMinLed(m_oClock.getMinute());
  setHourLed(m_oClock.getHour(m_bH12, m_bPM));

  oTLC.write();
 
  delay(200);
}

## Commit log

2021-10-19 kicad project setup
    [Berlin_Uhr.kicad_pcb, Berlin_Uhr.sch]
2021-10-19 first usable draft schematic
    [Berlin_Uhr.sch]
2021-10-23 circuit complete
    [Berlin_Uhr.sch]
2021-10-24 Schematic update
    - Lightsensor
    - I2C ADC
    [Berlin_Uhr.sch]
2021-10-26 Schematic update
    [Berlin_Uhr.sch]
2021-10-29 another schematic Update
    [Berlin_Uhr.sch]
2021-11-01 First PCB layout
    [Berlin_Uhr.kicad_pcb, Berlin_Uhr.sch]
2021-11-01 single PCB SVG
2021-11-01 update PCB
    [Berlin_Uhr.kicad_pcb]
2021-11-06 Update PCB
    improved layout
    [Berlin_Uhr.kicad_pcb]
2021-11-06 Update PCB
    USB track length symmetrical
    LED tracks to 0,35mm
    [Berlin_Uhr.kicad_pcb, Berlin_Uhr.sch]
2021-11-13 LED Frame added
    [Berlin_Uhr.kicad_pcb]
2021-11-14 PCB with silkscreen
    LED Side with grid
    Component Side with Image
    First Gerber Set
    [Berlin_Uhr-B_Cu.gbr, Berlin_Uhr-B_Mask.gbr, Berlin_Uhr-B_Paste.gbr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]
2021-11-15 PCB Update (getting close)
    this is getting close to be ordered
    [Berlin_Uhr-B_Cu.gbr, Berlin_Uhr-B_Mask.gbr, Berlin_Uhr-B_Paste.gbr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]
2021-11-21 add breakaway tabs for documentation
    [Berlin_Uhr.kicad_pcb]
2021-11-25 PCB to order
    [Berlin_Uhr-B_Cu.gbr, Berlin_Uhr-B_Mask.gbr, Berlin_Uhr-B_Paste.gbr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]
2021-12-11 * insert variables * read RTC * functions to set seconds, minutes, hours * write to TLC
2021-12-11 * add LED pin offset * correct pins for LEDs
    [berlin-uhr.ino]
2021-12-11 * add test funktion for LEDs
2021-12-11 * remove serial * delay in test funktions now a variable * bugfix in LED off function * write to TCL after set PWM
    [berlin-uhr.ino]
2021-12-11 * bugfix: 5h and 5min calc
    [berlin-uhr.ino]
2021-12-11 PCB Update / Bugfix after first Batch
    - R4 now a pullup for Blank, not pulldown
    - add text that the battery is a CR1216
    [Berlin_Uhr-B_Cu.gbr, Berlin_Uhr-B_Mask.gbr, Berlin_Uhr-B_Paste.gbr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]
2021-12-12 bom with latest ibom
    [Berlin_Uhr.kicad_pcb]
2021-12-12 * bugfix: 24h mode * add Button A & B to change time
    [berlin-uhr.ino]
2021-12-14 * bugfix: inc/dec min
    [berlin-uhr.ino]
2021-12-23 PCB Revision 2021 2
    fixed issues:
    - TLC5947 Blank pullup instead of pulldown
    - KPS-3227 footprint
    and some minor tweaks in routing
    [Berlin_Uhr-B_Cu.gbr, Berlin_Uhr-B_Mask.gbr, Berlin_Uhr-B_Paste.gbr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]
2022-01-12 * add light sensor
2022-01-15 PCB Update
    bugfix in footprint
    [Berlin_Uhr.kicad_pcb, Berlin_Uhr.kicad_sch]
2022-01-16 * add option for linear and log curve for brightness * bugfix linear minimum * add log curve
    [berlin-uhr.ino]
2022-01-16 * set default curve to linear * minimum for linear was wrong
    [berlin-uhr.ino]
2022-02-14 Switch KPS-3227 to native KiCad part.
    KiCad 6.0.2 fixed the KPS-3227 Footprint, now using the build in one.
    [Berlin_Uhr.kicad_pcb, Berlin_Uhr.kicad_sch]
2022-02-14 Update README.md
    clarify KiCad Version of at least 6.0.2 is needed for the KPS-3227 Bugfix
2022-02-26 Clean up project from old KiCad 5 only files
    this files are not needed in KiCad 6 anymore
    [Berlin_Uhr.sch]
2022-07-06 add schematic link

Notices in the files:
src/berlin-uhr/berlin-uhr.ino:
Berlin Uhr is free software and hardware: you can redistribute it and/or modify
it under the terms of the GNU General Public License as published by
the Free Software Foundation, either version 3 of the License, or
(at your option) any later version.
